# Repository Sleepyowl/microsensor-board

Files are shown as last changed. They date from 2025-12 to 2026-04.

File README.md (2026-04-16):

# Microsensor Board

This is a complete KiCad project of a miniature multiprotocol temperature and humidity sensor based on nRF54 SoC and HDC2080 sensor.

An example firmware for the board can be found here: [microsensor-firmware](https://github.com/Sleepyowl/microsensor-firmware).

# Features

- 4 layer PCB layout
    - NB: earlier versions routed with 2 layers
- External RTC allows System Off sleep enabling ultra-low power consumption
- SoC supports BLE, ZigBee and Thread
- Miniature 6-pin Tag-Connect for firmware burning and debugging
- Button and LED
- Backside pads for CR20xx

# Issues

- No reverse polarity or overvoltage protection (I don't need it for my application)

# Manufacturing

I have manufactured working prototypes on PCBWay with the following parameters:

| Parameter | Value |
|---|---|
| Layers | 4 |
| Thickness | 1.6 mm |
| Min Track / Spacing | 4 / 4 mil |
| Min Hole Size | 0.3 mm |
| Surface Finish | ENIG |

While it is possile get working boards with HASL lead-free, it might require manual retouching of some parts (e.g. RTC chip).

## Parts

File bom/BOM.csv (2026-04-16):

Reference | Value | Datasheet | Footprint | Qty | DNP
BT0 | CR1225 |  | footprints:Keystone 110 and 112 for CR20xx | 1
C1 | 220uF |  | Capacitor_SMD:C_1206_3216Metric | 1
C2,C3 | 0.1u |  | Capacitor_SMD:C_0805_2012Metric | 2
D1 | LED |  | LED_SMD:LED_1206_3216Metric | 1
Q1 | IRLML2244TRPBF | https://www.infineon.com/dgdl/irlml2244pbf.pdf?fileId=5546d462533600a401535664bfff25f0 | Package_TO_SOT_SMD:SOT-23 | 1
R1,R2,R9 | 4.7K |  | Resistor_SMD:R_0805_2012Metric | 3
R3,R6,R7 | 100K |  | Resistor_SMD:R_0805_2012Metric | 3
R4 | 330K |  | Resistor_SMD:R_0805_2012Metric | 1
R5,R8 | 100 |  | Resistor_SMD:R_0805_2012Metric | 2
SW1 | Control |  | footprints:B3U-1000P | 1
U1 | HDC2080 | http://www.ti.com/lit/ds/symlink/hdc2080.pdf | Sensor_Humidity:Texas_S-PWSON-N6-HDC2080 | 1
U2 | RV-3028-C7 | https://www.microcrystal.com/fileadmin/Media/Products/RTC/Datasheet/RV-3028-C7.pdf | Package_SON:MicroCrystal_C7_SON-8_1.5x3.2mm_P0.9mm | 1
U3 | NORA B206 |  | footprints:NORA-B2x6 | 1
Y1 | 32768 |  | Crystal:Crystal_SMD_2012-2Pin_2.0x1.2mm | 1

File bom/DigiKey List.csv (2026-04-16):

Indeks | Manufacturer Part Number | Beskrivelse | Attrition % | Ønsket mængde 1 | Pakkemængde 1 | Pakketype 1 | Digi-Keys varenummer 1 | Enhedspris 1 | Udvidet pris 1 | Minimum ordreantal 1 | Produktnoter
1 | GCJ21BR72A104KA01L | CAP CER 0.1UF 100V X7R 0805 |  | 2 | 2 | Cut Tape (CT) | 490-5825-1-ND | 0,24000 | 0,48 $ | 1
2 | QBLP615-R | LED RED CLEAR 1206 SMD R/A |  | 1 | 1 | Cut Tape (CT) | 1516-1076-1-ND | 0,32000 | 0,32 $ | 1
3 | IRLML2244TRPBF | MOSFET P-CH 20V 4.3A SOT23 |  | 1 | 1 | Cut Tape (CT) | IRLML2244TRPBFCT-ND | 0,42000 | 0,42 $ | 1
4 | ERJ-6ENF3303V | RES SMD 330K OHM 1% 1/8W 0805 |  | 1 | 1 | Cut Tape (CT) | P330KCCT-ND | 0,12000 | 0,12 $ | 1
5 | ERJ-6ENF1003V | RES SMD 100K OHM 1% 1/8W 0805 |  | 3 | 3 | Cut Tape (CT) | P100KCCT-ND | 0,12000 | 0,36 $ | 1
6 | ERJ-6ENF4701V | RES SMD 4.7K OHM 1% 1/8W 0805 |  | 3 | 3 | Cut Tape (CT) | P4.70KCCT-ND | 0,12000 | 0,36 $ | 1
7 | B3U-1000P | SWITCH TACTILE SPST-NO 0.05A 12V |  | 1 | 1 | Cut Tape (CT) | SW1020CT-ND | 1,17000 | 1,17 $ | 1
8 | NORA-B206-00B | NRF54L15, PCB ANTENNA, OPEN CPU |  | 1 | 1 | Cut Tape (CT) | 672-NORA-B206-00BCT-ND | 6,43000 | 6,43 $ | 1
9 | RV-3028-C7 32.768KHZ 1PPM-TA-QA | IC RTC CLK/CALENDAR I2C 8SON |  | 1 | 1 | Cut Tape (CT) | 2195-RV-3028-C732.768KHZ1PPM-TA-QACT-ND | 2,64000 | 2,64 $ | 1
10 | Q 0,032768-JTX210-7-20-T1-HMR-70K-LF | XTAL 32.768KHZ 7PF 70KOHM SMD |  | 1 | 1 | Cut Tape (CT) | 1908-Q0,032768-JTX210-7-20-T1-HMR-70K-LFCT-ND | 0,37000 | 0,37 $ | 1
11 | HDC2080DMBR | SENSOR HUMIDITY |  | 1 | 1 | Cut Tape (CT) | 296-52638-1-ND | 2,02000 | 2,02 $ | 1
12 | GRM31CR60J227ME11L | CAP CER 220UF 6.3V X5R 1206 |  | 1 | 1 | Cut Tape (CT) | 490-13970-1-ND | 1,09000 | 1,09 $ | 1
13 | 110TR | BATT CONTACT SPRING MULTIPLE SMD |  | 1 | 1 | Cut Tape (CT) | 36-110CT-ND | 0,38000 | 0,38 $ | 1
14 | 112TR | BATT CONTACT SPRING MULTIPLE SMD |  | 1 | 1 | Cut Tape (CT) | 36-112CT-ND | 0,38000 | 0,38 $ | 1
15 | ERJ-P06J101V | RES SMD 100 OHM 5% 1/2W 0805 |  | 2 | 2 | Cut Tape (CT) | P100ADCT-ND | 0,14000 | 0,28 $ | 1

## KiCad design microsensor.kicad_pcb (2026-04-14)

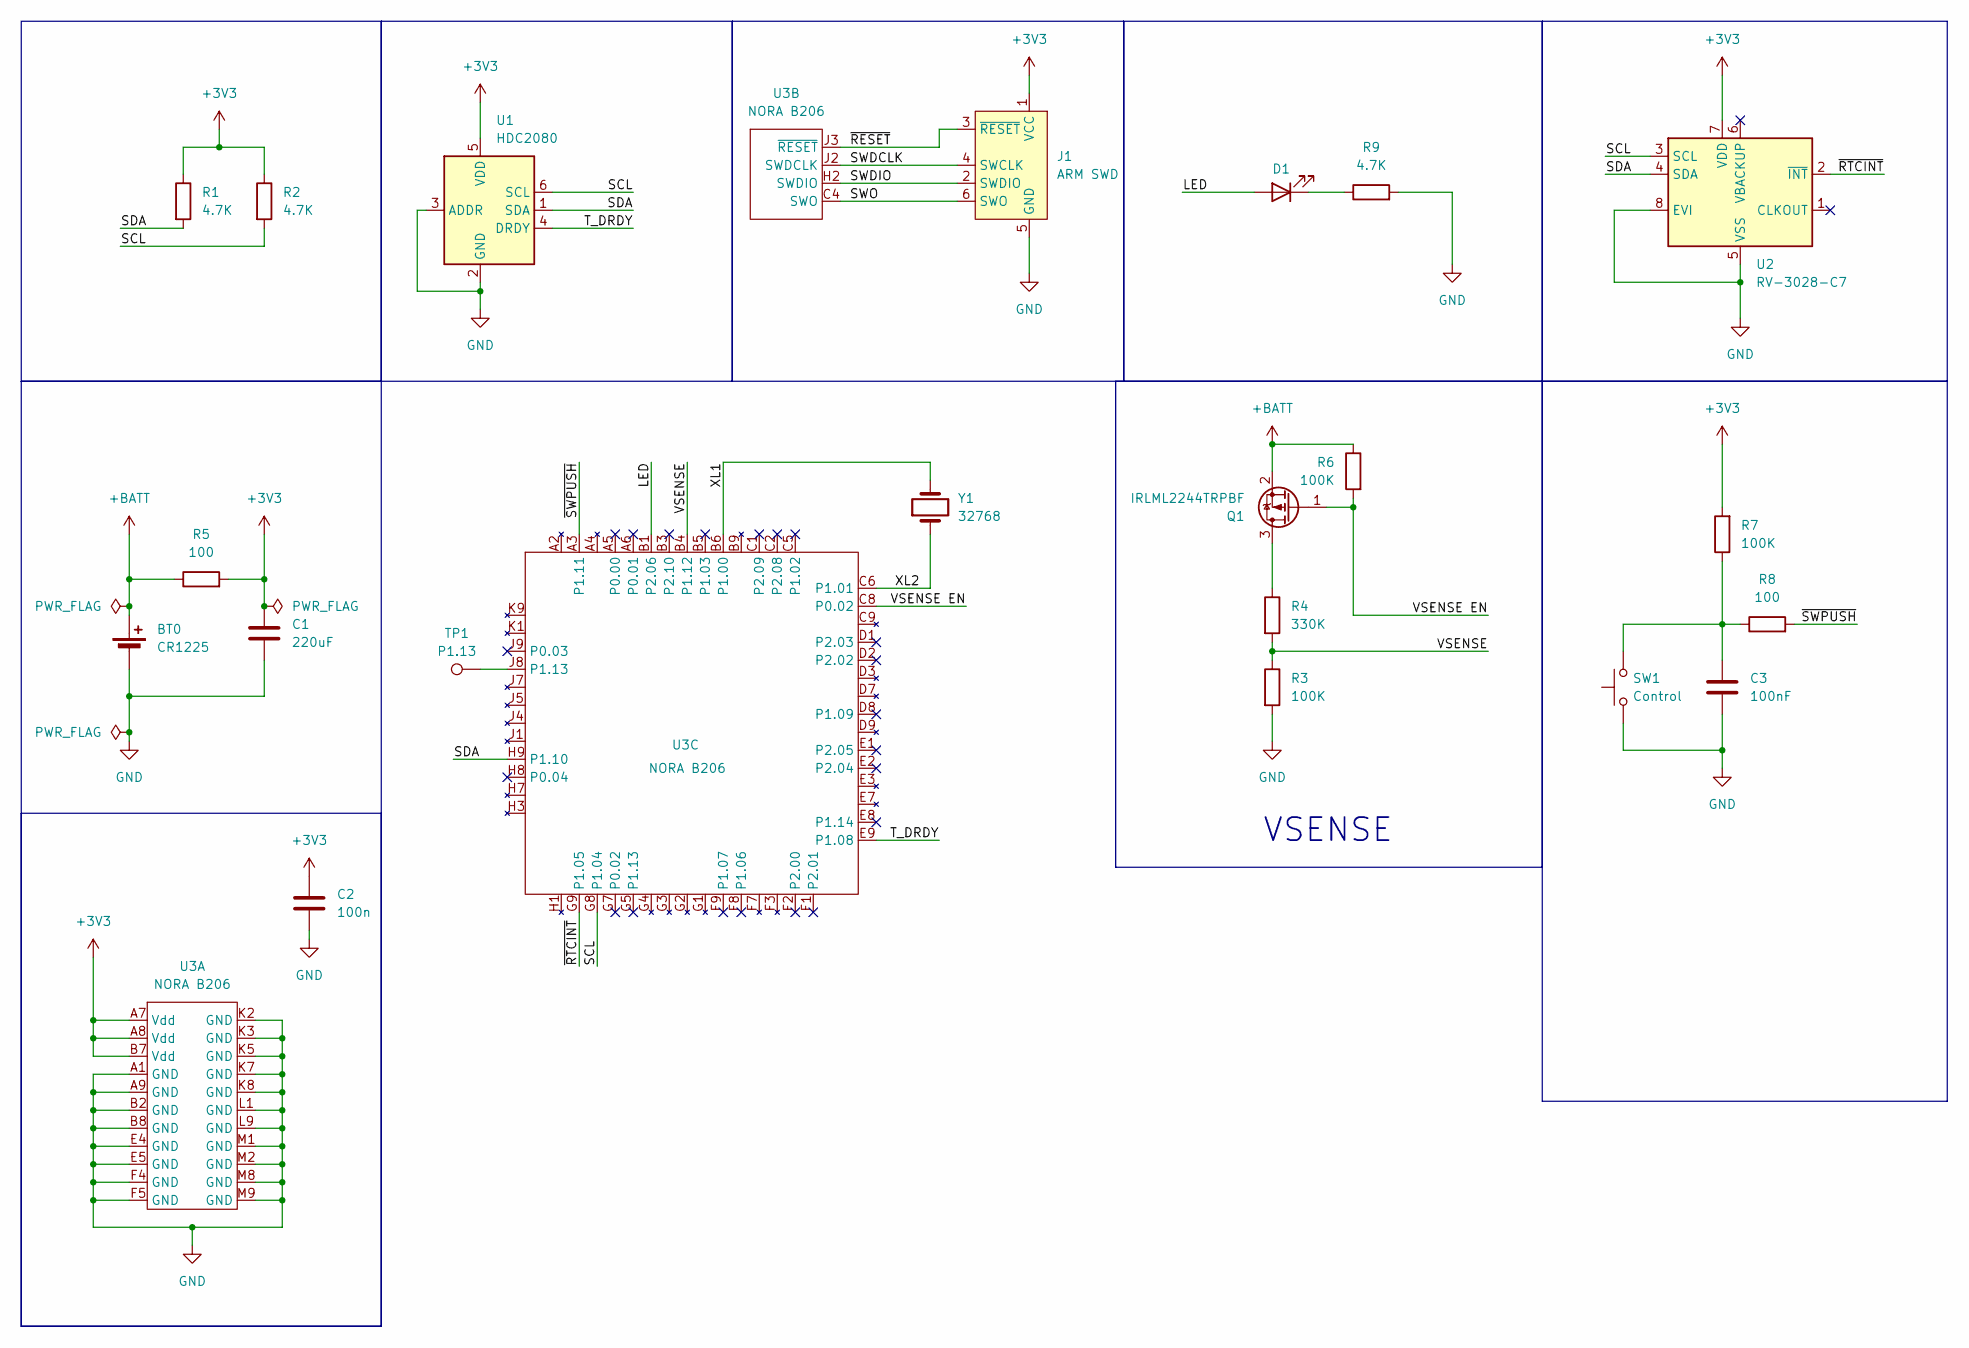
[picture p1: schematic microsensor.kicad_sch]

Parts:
BT0: CR1225; Keystone 110 and 112 for CR20xx
C1: 220uF; C_1206_3216Metric
C2: 100n; C_0805_2012Metric
C3: 100nF; C_0805_2012Metric
D1: LED; LED_1206_3216Metric
J1: ARM SWD; Tag-Connect_TC2030-IDC-NL_2x03_P1.27mm_Vertical
Q1: IRLML2244TRPBF; SOT-23
R1, R2, R9: 4.7K; R_0805_2012Metric
R3, R6, R7: 100K; R_0805_2012Metric
R4: 330K; R_0805_2012Metric
R5, R8: 100; R_0805_2012Metric
SW1: Control; B3U-1000P
TP1: P1.13; TestPoint_Pad_1.5x1.5mm
U1: HDC2080; Texas_S-PWSON-N6-HDC2080
U2: RV-3028-C7; MicroCrystal_C7_SON-8_1.5x3.2mm_P0.9mm
U3: NORA B206; NORA-B2x6
Y1: 32768; Crystal_SMD_2012-2Pin_2.0x1.2mm

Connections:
+3V3: C1.1, C2.1, J1.1 (VCC), R1.1, R2.1, R5.2, R7.2, U1.5 (VDD), U2.7 (VDD), U3.A7 (Vdd), U3.A8 (Vdd), U3.B7 (Vdd)
+BATT: BT0.1 (+), Q1.2 (S), R5.1, R6.1
/LED: D1.2 (A), U3.B1 (P2.06)
/SCL: R2.2, U1.6 (SCL), U2.3 (SCL), U3.G8 (P1.04)
/SDA: R1.2, U1.1 (SDA), U2.4 (SDA), U3.H9 (P1.10)
/SWDCLK: J1.4 (SWCLK), U3.J2 (SWDCLK)
/SWDIO: J1.2 (SWDIO), U3.H2 (SWDIO)
/SWO: J1.6 (SWO), U3.C4 (SWO)
/T_DRDY: U1.4 (DRDY), U3.E9 (P1.08)
/VSENSE: R3.1, R4.2, U3.B4 (P1.12)
/VSENSE EN: Q1.1 (G), R6.2, U3.C8 (P0.02)
/XL1: U3.B6 (P1.00), Y1.2
/XL2: U3.C6 (P1.01), Y1.1
/~RESET: J1.3 (~RESET), U3.J3 (~RESET)
/~RTCINT: U2.2 (~INT), U3.G9 (P1.05)
/~SWPUSH: R8.2, U3.A3 (P1.11)
GND: BT0.2 (-), C1.2, C2.2, C3.2, J1.5 (GND), R3.2, R9.2, SW1.1, U1.2 (GND), U1.3 (ADDR), U2.5 (VSS), U2.8 (EVI), U3.A1 (GND), U3.A9 (GND), U3.B2 (GND), U3.B8 (GND), U3.E4 (GND), U3.E5 (GND), U3.F4 (GND), U3.F5 (GND), U3.K2 (GND), U3.K3 (GND), U3.K5 (GND), U3.K7 (GND), U3.K8 (GND), U3.L1 (GND), U3.L9 (GND), U3.M1 (GND), U3.M2 (GND), U3.M8 (GND), U3.M9 (GND)
unnamed: C3.1, R7.1, R8.1, SW1.2
unnamed: D1.1 (K), R9.1
unnamed: Q1.3 (D), R4.1
unnamed: TP1.1 (1_1), U3.J8 (P1.13)

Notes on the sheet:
VSENSE

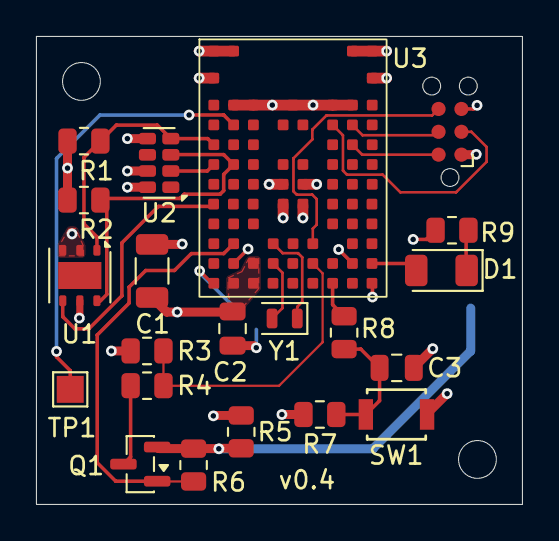
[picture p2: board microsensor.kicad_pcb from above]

Board: 4 copper layers, 27.0 x 26.0 mm, 24 parts (1 on the bottom side), 21 nets.

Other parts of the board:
MH1, MH2: MountingHole_2.1mm

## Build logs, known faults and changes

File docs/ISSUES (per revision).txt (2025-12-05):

PROBLEMS with revisions

v0.1
- no resistor between bulk cap and battery (still works though)
- RV2038 EVT pin is floating (higher current consumption)

v0.2
- i2c routed to invalid pins
	- nRF54 needs both on port1 and "clock-capable" pin for SCL
	- possible will work with both on port0 with &i2c30
	- "fixable" by sacrificing button and test point (used for UART TX)
- N-MOS is not needed on this board
	- fixable by bridging two pads of Q2
- Divider saturates nRF54 ADC with internal vref 
	- fixable with 100K resistor instead of 220K resistor

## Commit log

2025-10-23 Shrink to 45x35 Unify R sizes to 0805 Rearrange Add dimensions (User layer)
    [microsensor.kicad_pcb, microsensor.kicad_sch]
2025-10-23 Ver 0.1 finalized and ordered
    [microsensor.kicad_pcb]
2025-10-23 Added bom related properties
    [microsensor.kicad_sch]
2025-10-31 Add gerbers submitted for v0.1
2025-11-03 Smaller version 25mmx25mm
    [microsensor.kicad_pcb, microsensor.kicad_sch]
2025-11-06 Change battery holder, update layout
    [microsensor.kicad_pcb, microsensor.kicad_sch]
2025-11-08 Switch to nRF54L15 (NORA B206)
    [microsensor.kicad_pcb, microsensor.kicad_sch]
2025-11-25 Finalize routing for NORA module Add and route VSENSE circuit
    [microsensor.kicad_pcb, microsensor.kicad_sch]
2025-12-04 v0.2 gerbers
2025-12-05 v0.2 BOM + document with issues
    [microsensor.kicad_sch]
2025-12-09 Fix I2C routed to invalid pins Remove unnecessary N-MOS Adjust placement and routing Adjust annotations (order topologically)
    [microsensor.kicad_pcb, microsensor.kicad_sch]
2025-12-09 Adjust board constraints Add CAM files for version 0.3
2026-04-14 v0.4 Switched to 4 layers Minor re-routing Changed button to smaller model Added mounting holes Added some missing 3d models
    [microsensor.kicad_pcb, microsensor.kicad_sch]
2026-04-16 Update BOM, add DigiKey list with parts
    [BOM.csv, DigiKey List.csv, microsensor.kicad_sch]
2026-04-16 Update thickness in README (was the value for 2L board)
